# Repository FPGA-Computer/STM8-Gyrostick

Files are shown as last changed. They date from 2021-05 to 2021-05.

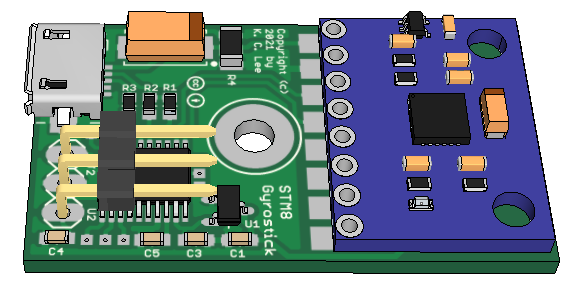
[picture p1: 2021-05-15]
hardware/stm8-accelerometer (sketchup 3D model).png

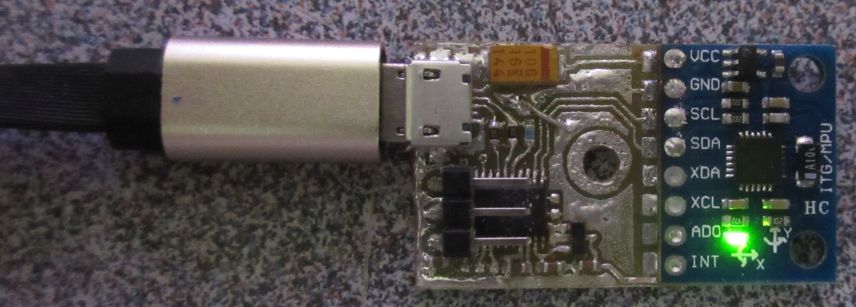
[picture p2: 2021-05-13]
pcb.jpg

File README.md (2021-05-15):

# STM8 Gyrostick

This is a USB HID game controller inspired by [Cemu Gyro Joystick](https://github.com/ArsenicBismuth/Cemu-GyroStick) project. 
The hardware is based on cheap [MPU6050 modules](http://wiki.sunfounder.cc/index.php?title=MPU6050_Module) used by [Gyro_Joystick](https://github.com/ArsenicBismuth/Arduino-Programs/tree/master/Gyro_Joystick).

It uses a firmware based USB library on a STM8S003 similar to VUSB and has to live with the HID report limitations of 8 bytes for low speed devices. The 3 Accelerometers and 3 Gyroscopes are grouped logically under their own reportIDs and takes turn being sent.
There is a long list of STM8 I2C peripheral errata, so I have no choice but to base mine on ST's heavy IRQ code from [AN3281 - STM8 8-bit MCUs I2C optimized examples](https://www.st.com/en/embedded-software/stsw-stm8004.html).
A simple busy wait was all that was need to make both of them coexist.

[My project page](https://hw-by-design.blogspot.com/2021/05/stm8-gyrostock.html)

# STM8 VUSB

The firmware only USB stack is an unofficial fork from [STM8S-VUSB-KEYBOARD](https://github.com/BBS215/STM8S-VUSB-KEYBOARD)

- Works with current special edition of Cosmic C (4.4.10) and current version of STVD (4.3.12)

Note: 

The USB stack calibrates the HSI clock while connected to the PC. The calibration is store in EEPROM. It may take a couple of minutes the first time before it functions correctly.

# Licenses

Hardware
- designed by me.  License under Creative Common Attribution 4.0 International [CC BY 4.0](https://creativecommons.org/licenses/by/4.0/)

Firmware
- Code written by me: [GPL 3.0](https://www.gnu.org/licenses/gpl-3.0.en.html)

3rd party firmware used
- STM8 USB stack is under [GPL-2.0](https://www.gnu.org/licenses/old-licenses/gpl-2.0.en.html). It is based on work by [Github user BBS215](https://github.com/BBS215)
- MPU6050.h header file by Harinadha Reddy Chintalapalli <harinath.ec@gmail.com> is under [MIT license ](https://mit-license.org/)
- ST STM8 header file under "MCD-ST Liberty SW License Agreement V2" text [here](https://www.st.com/content/ccc/resource/legal/legal_agreement/license_agreement/group0/59/57/63/12/cf/a6/47/65/SLA0044/files/SLA0044.txt/jcr:content/translations/en.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)
- I2C library are released as a published app. note by ST MCD Application Team. They can be used by ST STM8 customers.  I modified and cleaned up their code and not claiming copyright.

Initial release -  WIP.  Hardware working with Windows, but not picked up by Cemu software. Hard to debug the massive amount of Node.JS framework brought in by CEMU without *any* documentations

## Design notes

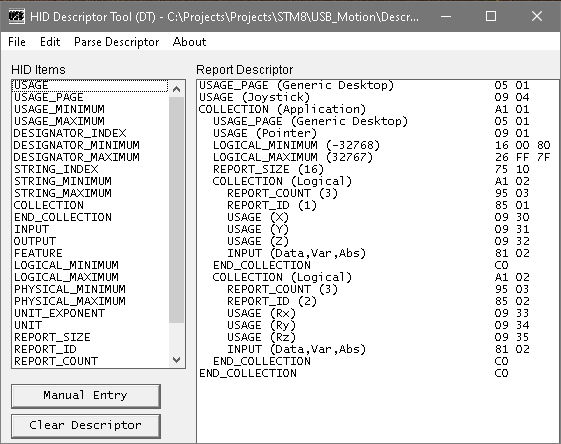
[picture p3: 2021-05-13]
software/USB HID firmware/Descriptor Tool V2.4/HID Report.png

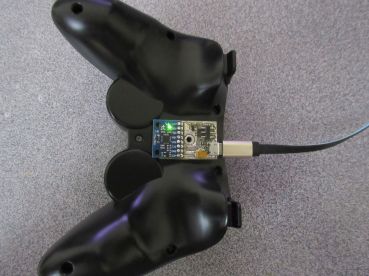
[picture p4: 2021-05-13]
controller.jpg

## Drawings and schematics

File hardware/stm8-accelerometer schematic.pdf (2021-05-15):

A

A

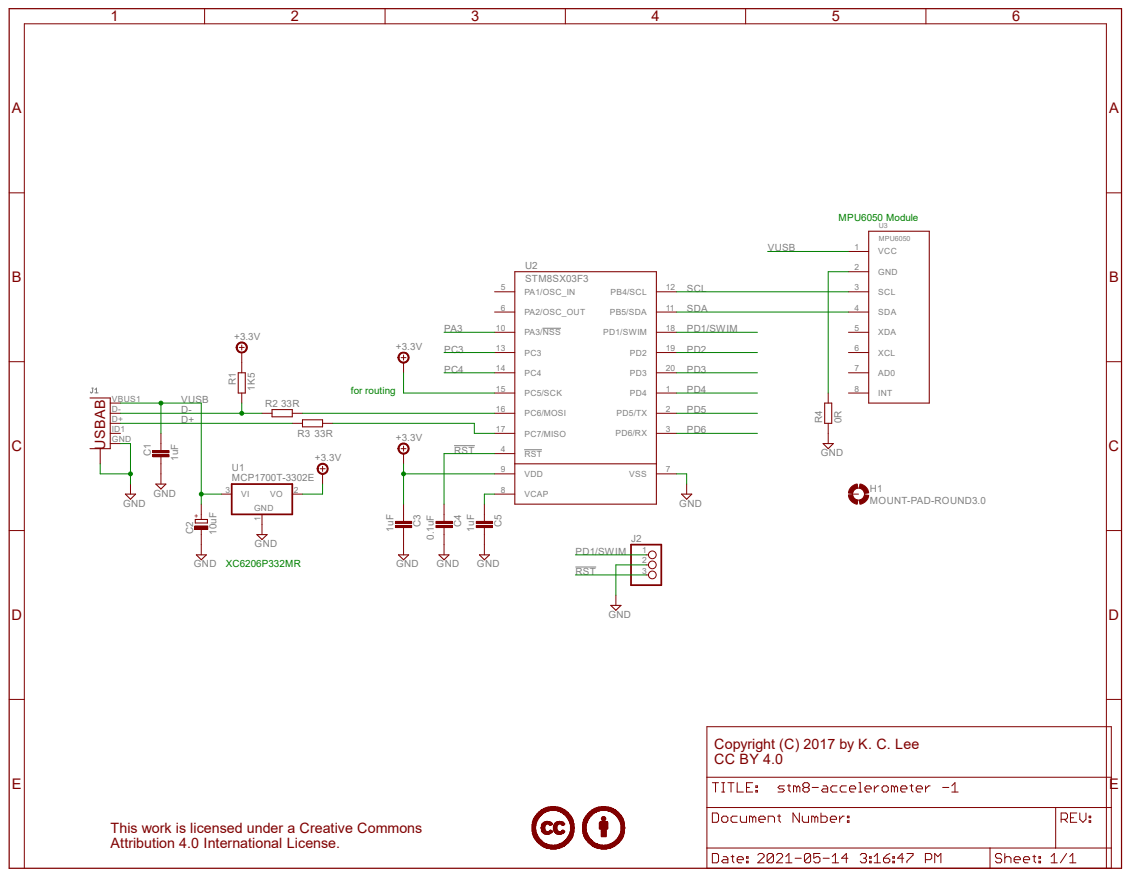
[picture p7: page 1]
33R ¹K⁵; GND; MCP1700T-3302E; GND ¹uF; STM8SX03F3 0.1uF; MOUNT-PAD-ROUND3.0; MPU6050 0R; U1 GND; PC6/MOSI 16; PC7/MISO 17; PC5/SCK 15; PA3/NSS 10; PB4/SCL; 12 PB5/SDA; 19 VDD 9; VCAP 8; VSS; 7 PD1/SWIM; 18 RST 4; PA1/OSC_IN 5; PA2/OSC_OUT 6; VCC 1; GND 2; SCL 3; SDA 4; XDA 5; XCL 6; INT 8; U3 R⁴D-; VUSB; RST; PD1/SWIM; SCL; SDA; 6 USBAB; for routing; MPU6050 Module

D+ D- VBUS1 GND

ID1 | | +3.3V RST

Copyright (C) 2017 by K. C. Lee

This work is licensed under a Creative Commons
Attribution 4.0 International License.

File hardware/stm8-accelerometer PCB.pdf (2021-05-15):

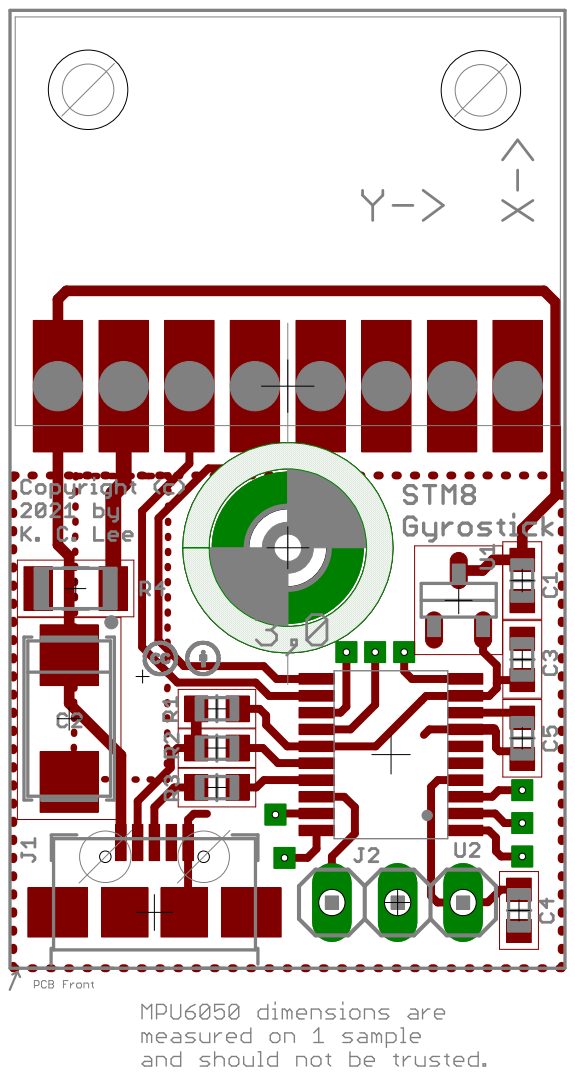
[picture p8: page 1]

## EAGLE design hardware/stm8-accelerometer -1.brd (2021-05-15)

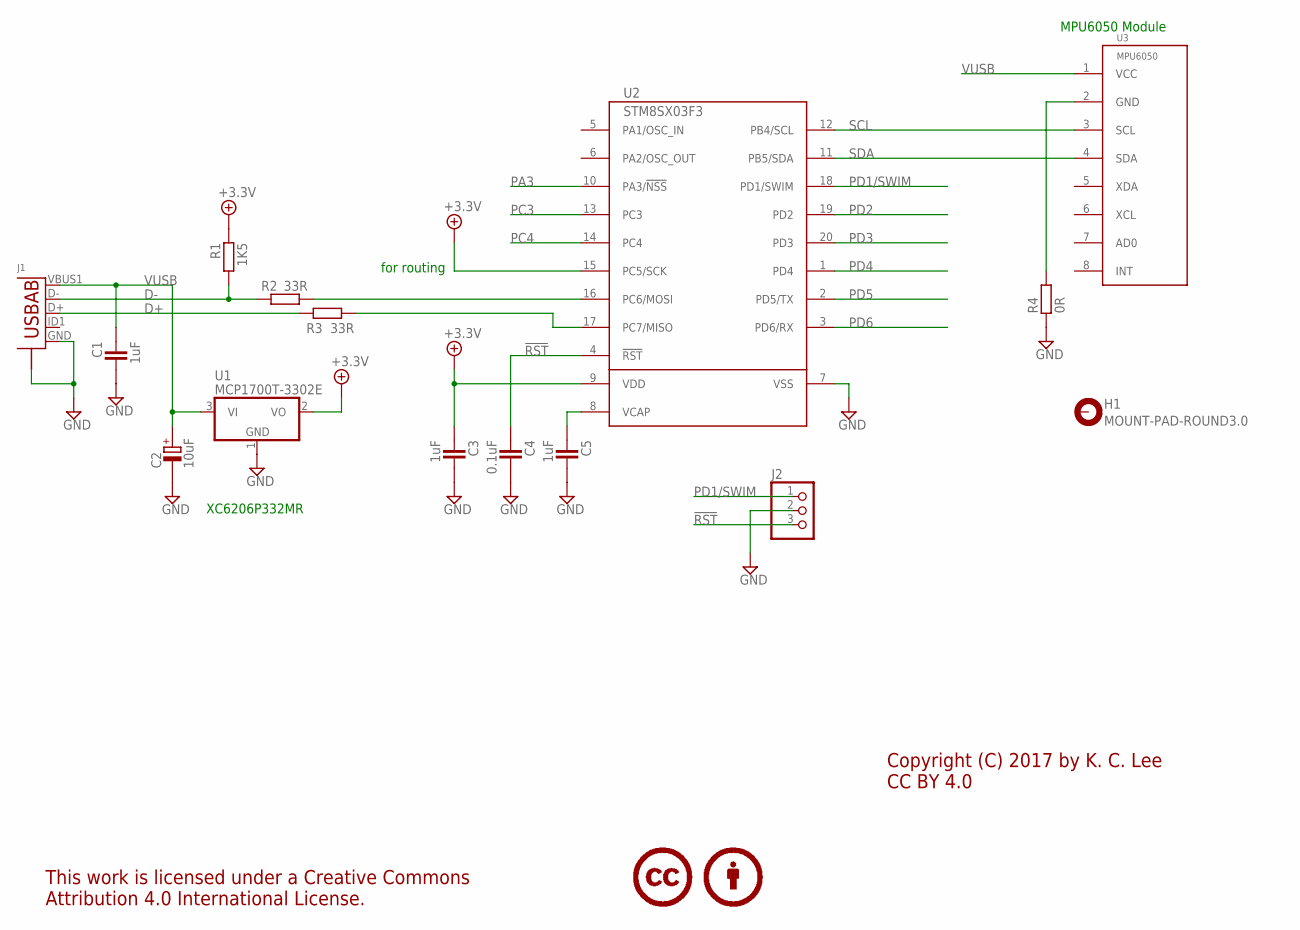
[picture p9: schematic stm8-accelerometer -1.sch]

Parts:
C1: 1uF; CAPC1608X92N; PARTNO NC 0805
C2: 10uF; CAPMP6032X280N; PARTNO 1uF X7R 0603
C3, C5: 1uF; CAPC1608X92N; PARTNO 1uF X7R 0603
C4: 0.1uF; CAPC1608X92N; PARTNO 1uF X7R 0603
H1: MOUNT-PAD-ROUND3.0; 3,0-PAD
J1: USB-ABBG-ORG; USB-AB-MICRO-SMD_V03_SMT
J2: PINHD-1X3_2.54; 1X03
LICENSE1: CC-BY50%; CC-BY-50
R1: 1K5; RESC1608X55N; PARTNO 1K5 0603
R2, R3: 33R; RESC1608X55N; PARTNO 47R 0603
R4: 0R; RESC3115X70N
U1: MCP1700T-3302E; SOT95P280X135-3N; PARTNO MCP1700T-3302E/TT
U2: STM8SX03F3; TSSOP20
U3: MPU6050

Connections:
!RST: C4.1, J2.3, U2.4 (!RST)
+3.3V: C3.1, R1.1, U1.2 (VO), U2.9 (VDD), U2.15 (PC5/SCK)
D+: J1.D+, R3.1
D-: J1.D-, R1.2, R2.1
GND: C1.2, C2.-, C3.2, C4.2, C5.2, J1.GND, J1.S1 (S), J1.S2 (S), J1.S3 (S), J1.S4 (S), J2.2, R4.1, U1.1 (GND), U2.7 (VSS)
unnamed: R4.2, U3.2 (GND)
unnamed: C5.1, U2.8 (VCAP)
unnamed: R3.2, U2.17 (PC7/MISO)
unnamed: R2.2, U2.16 (PC6/MOSI)
PA3: U2.10 (PA3/!NSS)
PC3: U2.13 (PC3)
PC4: U2.14 (PC4)
PD1/SWIM: J2.1, U2.18 (PD1/SWIM)
PD2: U2.19 (PD2)
PD3: U2.20 (PD3)
PD4: U2.1 (PD4)
PD5: U2.2 (PD5/TX)
PD6: U2.3 (PD6/RX)
SCL: U2.12 (PB4/SCL), U3.3 (SCL)
SDA: U2.11 (PB5/SDA), U3.4 (SDA)
VUSB: C1.1, C2.+, J1.VBUS1 (VBUS), U1.3 (VI), U3.1 (VCC)

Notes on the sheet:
Copyright (C) 2017 by K. C. Lee CC BY 4.0
XC6206P332MR
for routing
MPU6050 Module

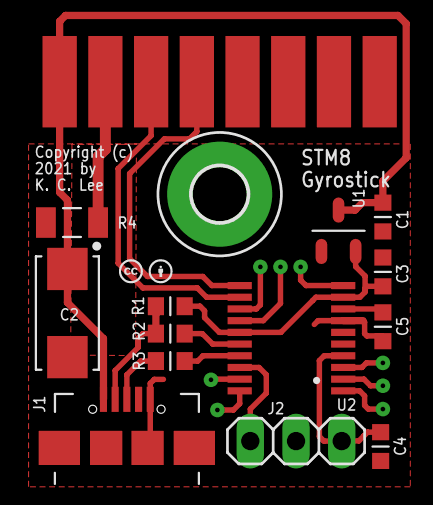
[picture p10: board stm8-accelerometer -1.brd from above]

Board: 2 copper layers, 16 parts (0 on the bottom side), 13 nets.

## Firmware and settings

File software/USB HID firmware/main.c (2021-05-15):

#include "usb.h"
#include "hardware.h"

/*
	USB_EP0_RxReady_callback is pre-assigned for data processing,
	EP0 in the Data stage process.
*/

void USB_EP0_RxReady_callback(uint8_t *p_data, uint8_t length)
{
}

/*
USB_Class_Init_callback is called upon initiation
USB powered device.
*/
int8_t USB_Class_Init_callback(uint8_t dev_config)
{
	MPU6050_State = USB_Rdy;
	return 0;
}

/*
	USB_Class_DeInit_callback is called upon reset.
	USB powered device.
*/
int8_t USB_Class_DeInit_callback(void)
{
	return 0;
}

/*
	USB_Setup_Request_callback is called for processing USB requests,
	Not included in the standard USB stack.
*/

int8_t USB_Setup_Request_callback(t_USB_SetupReq *p_req)
{	
	// HID Class GetReport
  if (((p_req->bmRequest&USB_REQ_TYPE_MASK)==USB_REQ_TYPE_CLASS) && 
			(p_req->bRequest==HID_REQ_GET_REPORT))
	{
		USB_Send_Data(NULL,0,0); 
		return 0;
	}
	
	return -1;
}

/*
	USB_EP1_RxReady_callback is pre-assigned for data processing,
  Pins EP1. In this example, it is not used.
*/
void USB_EP1_RxReady_callback(uint8_t *p_data, uint8_t length)
{
	// Nothing. Really.
}

/// MAIN ///////////////////////////////////////////////////

void main(void)
{
	uint8_t counter = TIM4_CNTMAX;
	
	Init_Hardware();

	while(1)
	{
		USB_loop(); // A "quick" USB loop for processing requests
		Motion_Task();
		
		if (TIM4->SR1 && TIM4_SR1_UIF)	// poll for TIM4 update
		{ 
			// clear update flag
			TIM4->SR1 = (uint8_t) ~TIM4_SR1_UIF;
			
			if (counter)
			{
				counter--;	
			}
			else
			{	// 100 Hz call
				USB_slow_loop(); // "slow" USB loop for setting HSI generator and EP1 watchdog
				counter = TIM4_CNTMAX;		
			}
		}
	}
}

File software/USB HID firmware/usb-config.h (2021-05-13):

#ifndef USB_CONFIG_H_
#define USB_CONFIG_H_

/// SETTINGS ///////////////////////////////////////////////
#define USB_MAX_NUM_CONFIGURATION 	1 // device configuration
#define USB_MAX_NUM_INTERFACES 			1 // device interfaces
#define USB_SELF_POWERED						0 // 0 - power from USB, 1 - dedicated power supply
#define USB_CLOCK_HSI								1	// 0 - external frequency to 16 MHz (PA1, PA2); 1 - from the internal RC generator (HSI)
//#define USB_CLOCK_HSI							0
#define USB_CONNECT_TIMEOUT					700 // connection timeout before reset // 100Hz * 7 sec = 700
#define USB_RECONNECT_DELAY					100 // 100Hz * 1 sec = 100

#define USB_RESET_DELAY							2000		// time to detect "USB RESET" // 5-7ms
//#define USB_EP_WATCHDOG_ENABLE			1 		// when EP is unavailable
#define USB_EP_WATCHDOG_TIMEOUT			300 		// timeout 3 sec
#define USB_EP_WATCHDOG_RECONNECT_DELAY	100 // Delay between switching off and on // 100Hz * 1 sec = 100

#define EEPROM_START_ADDR						0x4000 	// EEPROM location where the HSI flask and HSITRIM value are written (2 bytes)
#define MAGIC_VAL										0x11 		// HSI setup flag. If the EEPROM contains a different value, the HSI setting will start at zero.

// Optional features
#define USB_CFG_HID_DESCRIPTORS							// handle USB HID descriptors

//#define USB_CFG_FEATURES_SUPPORT					// Support Set/Clear feature

#endif

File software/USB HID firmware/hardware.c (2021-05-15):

/*
 * hardware.c
 *
 * Created: May 10, 2021, 1:59:19 PM
 *  Author: K. C. Lee
 * Copyright (c) 2021 by K. C. Lee
 
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
 If not, see http://www.gnu.org/licenses/gpl-3.0.en.html 
 */ 

#include "hardware.h"
#include "usb.h"

void Init_Hardware(void)
{	
	Check_OPTION_BYTE();
	CLK->CKDIVR = 0; // HSIDIV = 0; CPUDIV = 0
		
	USB_disconnect();
	TIM4_Init();
	I2C_Init();
	USB_Init();
	Delay(US_DELAY(90000));
	enableInterrupts();
	MPU6050_Init();	
	USB_connect();
}

#define IWDG_KEY_ENABLE 0xcc

void RESET_CHIP(void)
{
	IWDG->KR = IWDG_KEY_ENABLE; // Reset the CPU: Enable the watchdog and wait until it expires
	while(1);    // Wait until reset occurs from IWDG
}

void FLASH_Data_lock(uint8_t lock)
{
	if(lock)
		FLASH->IAPSR = 0;
	else
	{
		/* Warning: keys are reversed on data memory !!! */
    FLASH->DUKR = FLASH_RASS_KEY2;
    FLASH->DUKR = FLASH_RASS_KEY1;		
	}
}

void FLASH_Wait(void)
{
	while(!(uint8_t)(FLASH->IAPSR & (FLASH_IAPSR_EOP | FLASH_IAPSR_WR_PG_DIS)))
		/* wait*/;
}

void Check_OPTION_BYTE(void)
{
	uint8_t option_byte;

	if ((OPT->OPT2 != (uint8_t)(~OPT->NOPT2))||((OPT->OPT2 & AFR0) == 0)) 
	{ // check AFR0
		option_byte = OPT->OPT2|AFR0; 		// set AFR0 = 1 // PORT C[7..5] Alternate Function
		
		FLASH_Data_lock(0);
		FLASH->CR2 |= FLASH_CR2_OPT;
		FLASH->NCR2 &= (uint8_t)(~FLASH_NCR2_NOPT);

		OPT->OPT2 = option_byte;
		FLASH_Wait();

		OPT->NOPT2 = (uint8_t)(~option_byte);
		FLASH_Wait();
		
		// Disable write access to option bytes
		FLASH->CR2 &= (uint8_t)(~FLASH_CR2_OPT);
		FLASH->NCR2 |= FLASH_NCR2_NOPT;

		FLASH_Data_lock(1);
    RESET_CHIP();
	}
	
	if ((OPT->OPT3 != (uint8_t)(~OPT->NOPT3))||((OPT->OPT3 & HSITRIM) == 0)) 
	{ // check HSITRIM
		option_byte = OPT->OPT3|HSITRIM;			// 4 bit on-the-fly trimming
		
		FLASH_Data_lock(0);
		FLASH->CR2 |= FLASH_CR2_OPT;
		FLASH->NCR2 &= (uint8_t)(~FLASH_NCR2_NOPT);

		OPT->OPT3 = option_byte;
		FLASH_Wait();

		OPT->NOPT3 = (uint8_t)(~option_byte);
		FLASH_Wait();
		
		// Disable write access to option bytes
		FLASH->CR2 &= (uint8_t)(~FLASH_CR2_OPT);
		FLASH->NCR2 |= FLASH_NCR2_NOPT;
		FLASH_Data_lock(1);
    RESET_CHIP();
	}
}

void TIM4_Init(void)
{
	TIM4->ARR = TIM4_RELOAD;
	TIM4->PSCR = TIM4_PRSC;
	// Counter Enable
	TIM4->CR1 = TIM4_CR1_CEN;
}

void Short_Delay(void)
{
		_asm("nop");
		_asm("nop");
		_asm("nop");
		_asm("nop");
		_asm("nop");	
		_asm("nop");		
}

// Use US_DELAY(X) to set value in us.  Maximum is ~104ms
void Delay(uint16_t t)
{
	for(;t;t--)
		Short_Delay();
}

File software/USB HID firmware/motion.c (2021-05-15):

/*
 * motion.c
 *
 * Created: May 11, 2021, 8:31:16 AM
 *  Author: K. C. Lee
 * Copyright (c) 2021 by K. C. Lee
 
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
 If not, see http://www.gnu.org/licenses/gpl-3.0.en.html 
 */ 
 
#include "hardware.h"
#include "usb.h"

uint8_t Report_Acc[REPORT_SIZE],Report_Gyro[REPORT_SIZE];
uint8_t ReportID = ID_Acc;

int16_t MPU6050_Regs[MPU6050_REGSIZE/2];
uint8_t MPU6050_State = USB_Idle;

// Init table values in pairs: (addr, value)
const uint8_t MPU6050_InitValues[]=
{
	// Cycle mode, clock source = X axis gyro
	MPU6050_RA_PWR_MGMT_1,MPU6050_PWR1_CYCLE_BIT|1,
	// Low pass filter = 42Hz
	MPU6050_RA_CONFIG,MPU6050_DLPF_BW_42,
	
	//Accelerometer: +/- 2g
	//MPU6050_RA_ACCEL_CONFIG,MPU6050_ACCEL_FS_2<<MPU6050_GCONFIG_FS_SEL_BIT-1,
	
	// Gyro: +/- 1000 deg/s
	MPU6050_RA_GYRO_CONFIG,MPU6050_GYRO_FS_1000<<MPU6050_GCONFIG_FS_SEL_BIT-1,
};

void MPU6050_Init(void)
{
	uint8_t i;

	for(i=0;i<sizeof(MPU6050_InitValues);i+=2)
	{
		I2C_Write(MPU6050_ADDRESS_AD0_LOW,&MPU6050_InitValues[i],2);
		I2C_Busy(I2C_WAIT);
	}
	
	Report_Acc[Report_ID]= ID_Acc;
	Report_Gyro[Report_ID]= ID_Gyro;
}

void UpdateReport(uint8_t *Report,uint8_t Index,int32_t Value)
{
	int16_t Value16;

	// clip scaled values to int16
	if(Value > S16_MAX)
		Value = S16_MAX;
	else if(Value < S16_MIN)
		Value = S16_MIN;
	
 Report[Index] = Value & 0x00ff; 
 Report[Index+1] = Value >> 8;
}

void MPU6050_Scale(void)
{	
	// scale and transfer to reports
	UpdateReport(Report_Acc,Report_X,MPU6050_Regs[RAW_Acc_Y]*ACCEL_XY_SCALE);
	UpdateReport(Report_Acc,Report_Y,MPU6050_Regs[RAW_Acc_X]*ACCEL_XY_SCALE);
	UpdateReport(Report_Acc,Report_Z,MPU6050_Regs[RAW_Acc_Z]*ACCEL_Z_SCALE);
	
	UpdateReport(Report_Gyro,Report_X,-MPU6050_Regs[RAW_Gyro_Y]*GYRO_SCALE);
	UpdateReport(Report_Gyro,Report_Y,-MPU6050_Regs[RAW_Gyro_X]*GYRO_SCALE);
	UpdateReport(Report_Gyro,Report_Z,-MPU6050_Regs[RAW_Gyro_Z]*GYRO_SCALE);
}

void Motion_Task(void)
{
	if(USB_Tx_Ready(EP1))		
		switch(MPU6050_State)
		{
			case USB_Rdy:
				Delay(USB_IDLE_DELAY);		// wait until USB packet is done, so it won't interfere with I2C
				I2C_Read(MPU6050_ADDRESS_AD0_LOW,MPU6050_RA_ACCEL_XOUT_H,(uint8_t*)MPU6050_Regs,MPU6050_REGSIZE);
				MPU6050_State = MPU6050_I2C_Read;
				break;
				
			case MPU6050_I2C_Read:
				if (!I2C_Busy(I2C_POLL))
				{ 
					MPU6050_Scale();
					
					// Alternate sending each of the reports
					if(ReportID == ID_Acc)
					{
						USB_Send_Data(Report_Acc,REPORT_SIZE,EP1);
						ReportID = ID_Gyro;
					}
					else
					{
						USB_Send_Data(Report_Gyro,REPORT_SIZE,EP1);
						ReportID = ID_Acc;
					}
					MPU6050_State = USB_Rdy;
				}
		}
}

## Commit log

2021-05-13 first commit - firmware is WIP upload later
    [stm8-accelerometer -1.brd, stm8-accelerometer -1.sch]
2021-05-15 Clean up. Still WIP
    [stm8-accelerometer -1.brd, stm8-accelerometer -1.sch]
2021-05-15 Add sketchup 3D model of PCB assembly
2021-05-15 Add sketchup 3D model of PCB assembly (PNG sample)

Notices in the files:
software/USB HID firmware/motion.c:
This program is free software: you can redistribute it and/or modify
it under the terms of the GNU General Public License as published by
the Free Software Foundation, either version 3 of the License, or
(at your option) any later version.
